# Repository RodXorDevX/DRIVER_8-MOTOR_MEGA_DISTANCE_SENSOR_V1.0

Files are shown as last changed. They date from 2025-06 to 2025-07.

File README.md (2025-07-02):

# DRIVER_8-MOTOR_MEGA_DISTANCE_SENSOR_V1.0

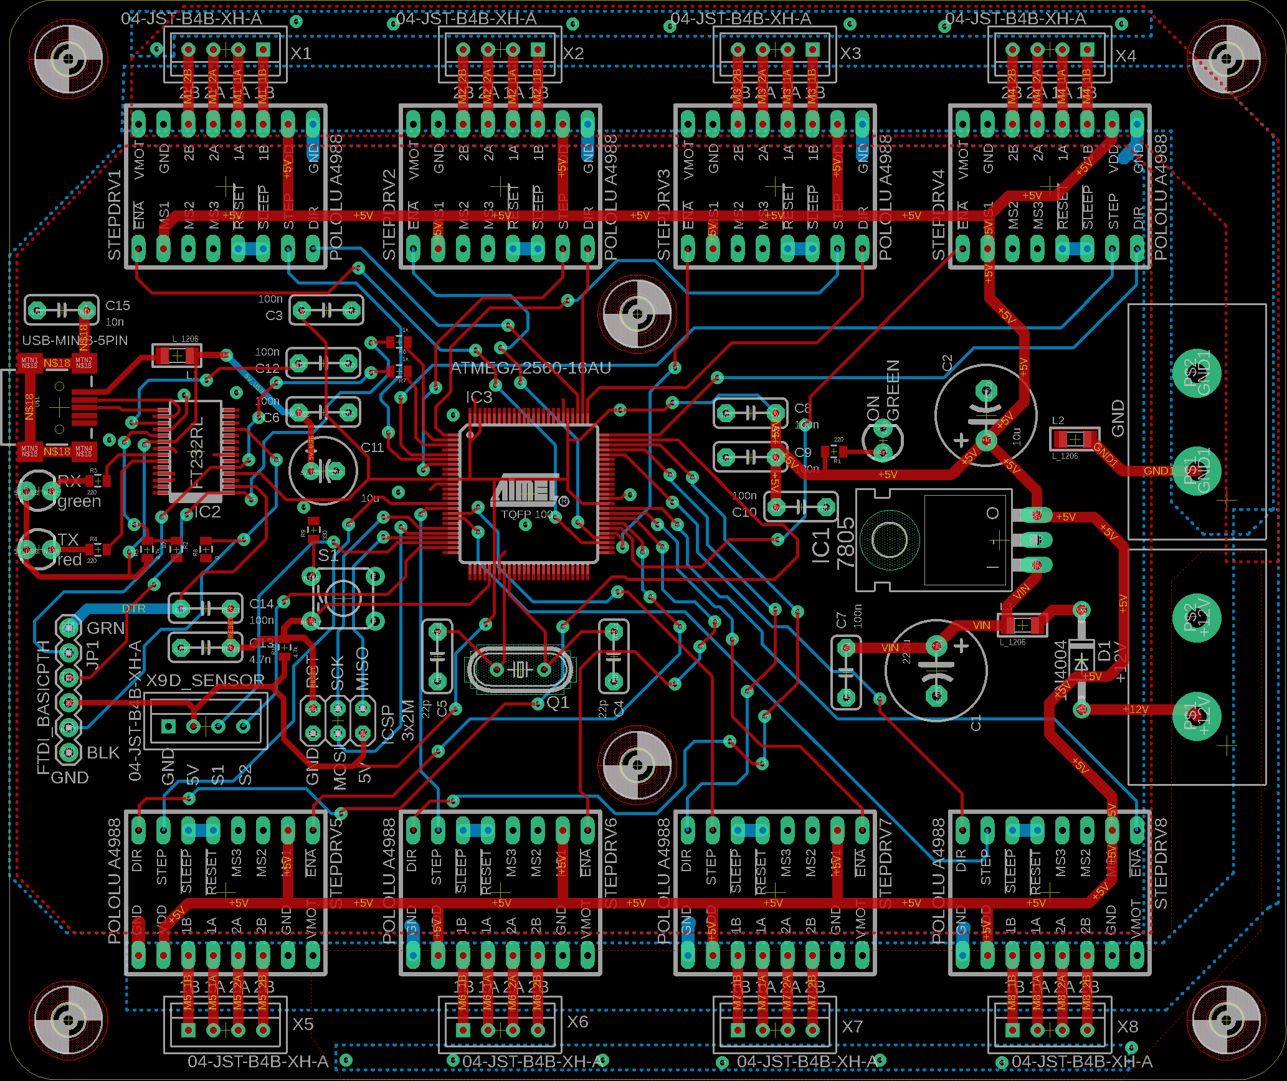
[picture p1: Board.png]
PCB

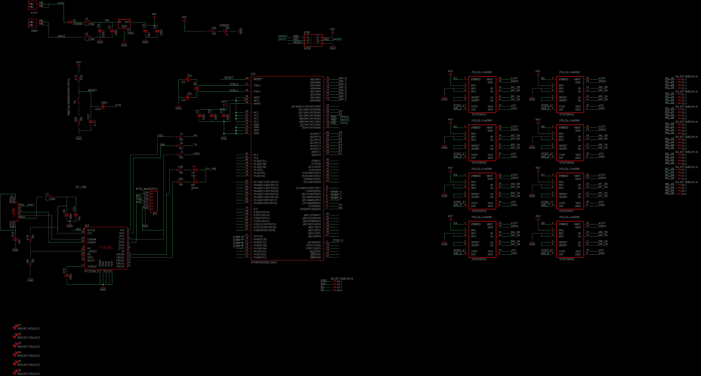
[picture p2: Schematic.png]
Esquemático


## Descripción

Este proyecto consiste en el diseño de una placa electrónica (PCB) para el control de hasta 8 motores y la integración de sensores de distancia, ideal para aplicaciones de robótica, automatización y sistemas embebidos. El diseño está basado en el microcontrolador ATMEGA2560, ampliamente utilizado en plataformas como Arduino MEGA, lo que facilita la programación y expansión del sistema.

La placa permite el uso de módulos para motores paso a paso como el Pololu A4988 o similares, y la conexión de sensores ultrasónicos para la detección de presencia o distancia.

## Aplicación artística

Esta placa fue utilizada en un proyecto de arte donde un cuadro contenía una figura de un anciano en bronce, cuyas partes se desarmaban automáticamente al detectar la presencia de una persona frente al cuadro mediante un sensor ultrasónico. Cuando no se detectaba presencia, el cuadro se rearmaba. También era posible invertir el comportamiento: el cuadro se reordenaba cuando había presencia.

## Características principales

- **Control de 8 motores:** Permite manejar hasta 8 motores de manera independiente mediante módulos A4988 o compatibles.
- **Sensores de distancia:** Integración sencilla de sensores ultrasónicos para medición de distancias o detección de presencia.
- **Microcontrolador ATMEGA2560:** 256 KB de memoria Flash, 8 KB de SRAM, 4 KB de EEPROM, 86 pines de I/O, 16 canales ADC de 10 bits, 12 canales PWM de 16 bits, 4 puertos USART.
- **Conectores estándar:** Pines y headers compatibles con módulos y shields comunes.
- **Archivos Gerber incluidos:** Listos para fabricación profesional de la PCB.

## Archivos incluidos

- `DRIVER_8 MOTOR_MEGA_DISTANCE_SENSOR_V1.0.sch`: Esquemático del circuito.
- `DRIVER_8 MOTOR_MEGA_DISTANCE_SENSOR_V1.0.brd`: Diseño de la PCB.
- Archivos Gerber (`.GBL`, `.GTL`, `.GBO`, `.GTO`, etc.): Para fabricación de la placa.
- `Board.png`: Imagen de la PCB.
- `Schematic.png`: Imagen del esquemático.
- `.TXT`, `.gpi`: Archivos de taladros y detalles de fabricación.

## Uso

1. **Revisión del diseño:** Consulta las imágenes incluidas para visualizar el esquemático y la PCB.
2. **Fabricación:** Utiliza los archivos Gerber para mandar a fabricar la placa en cualquier servicio profesional.
3. **Montaje:** Ensambla los componentes siguiendo el esquemático. Instala los módulos A4988 o similares en los zócalos correspondientes y conecta el sensor ultrasónico en el header designado.
4. **Programación:** Utiliza el entorno de Arduino o AVR para cargar el firmware al ATMEGA2560.

## Créditos

- Diseño original por Rodrigo Urquieta.
- Basado en el microcontrolador ATMEGA2560.

---

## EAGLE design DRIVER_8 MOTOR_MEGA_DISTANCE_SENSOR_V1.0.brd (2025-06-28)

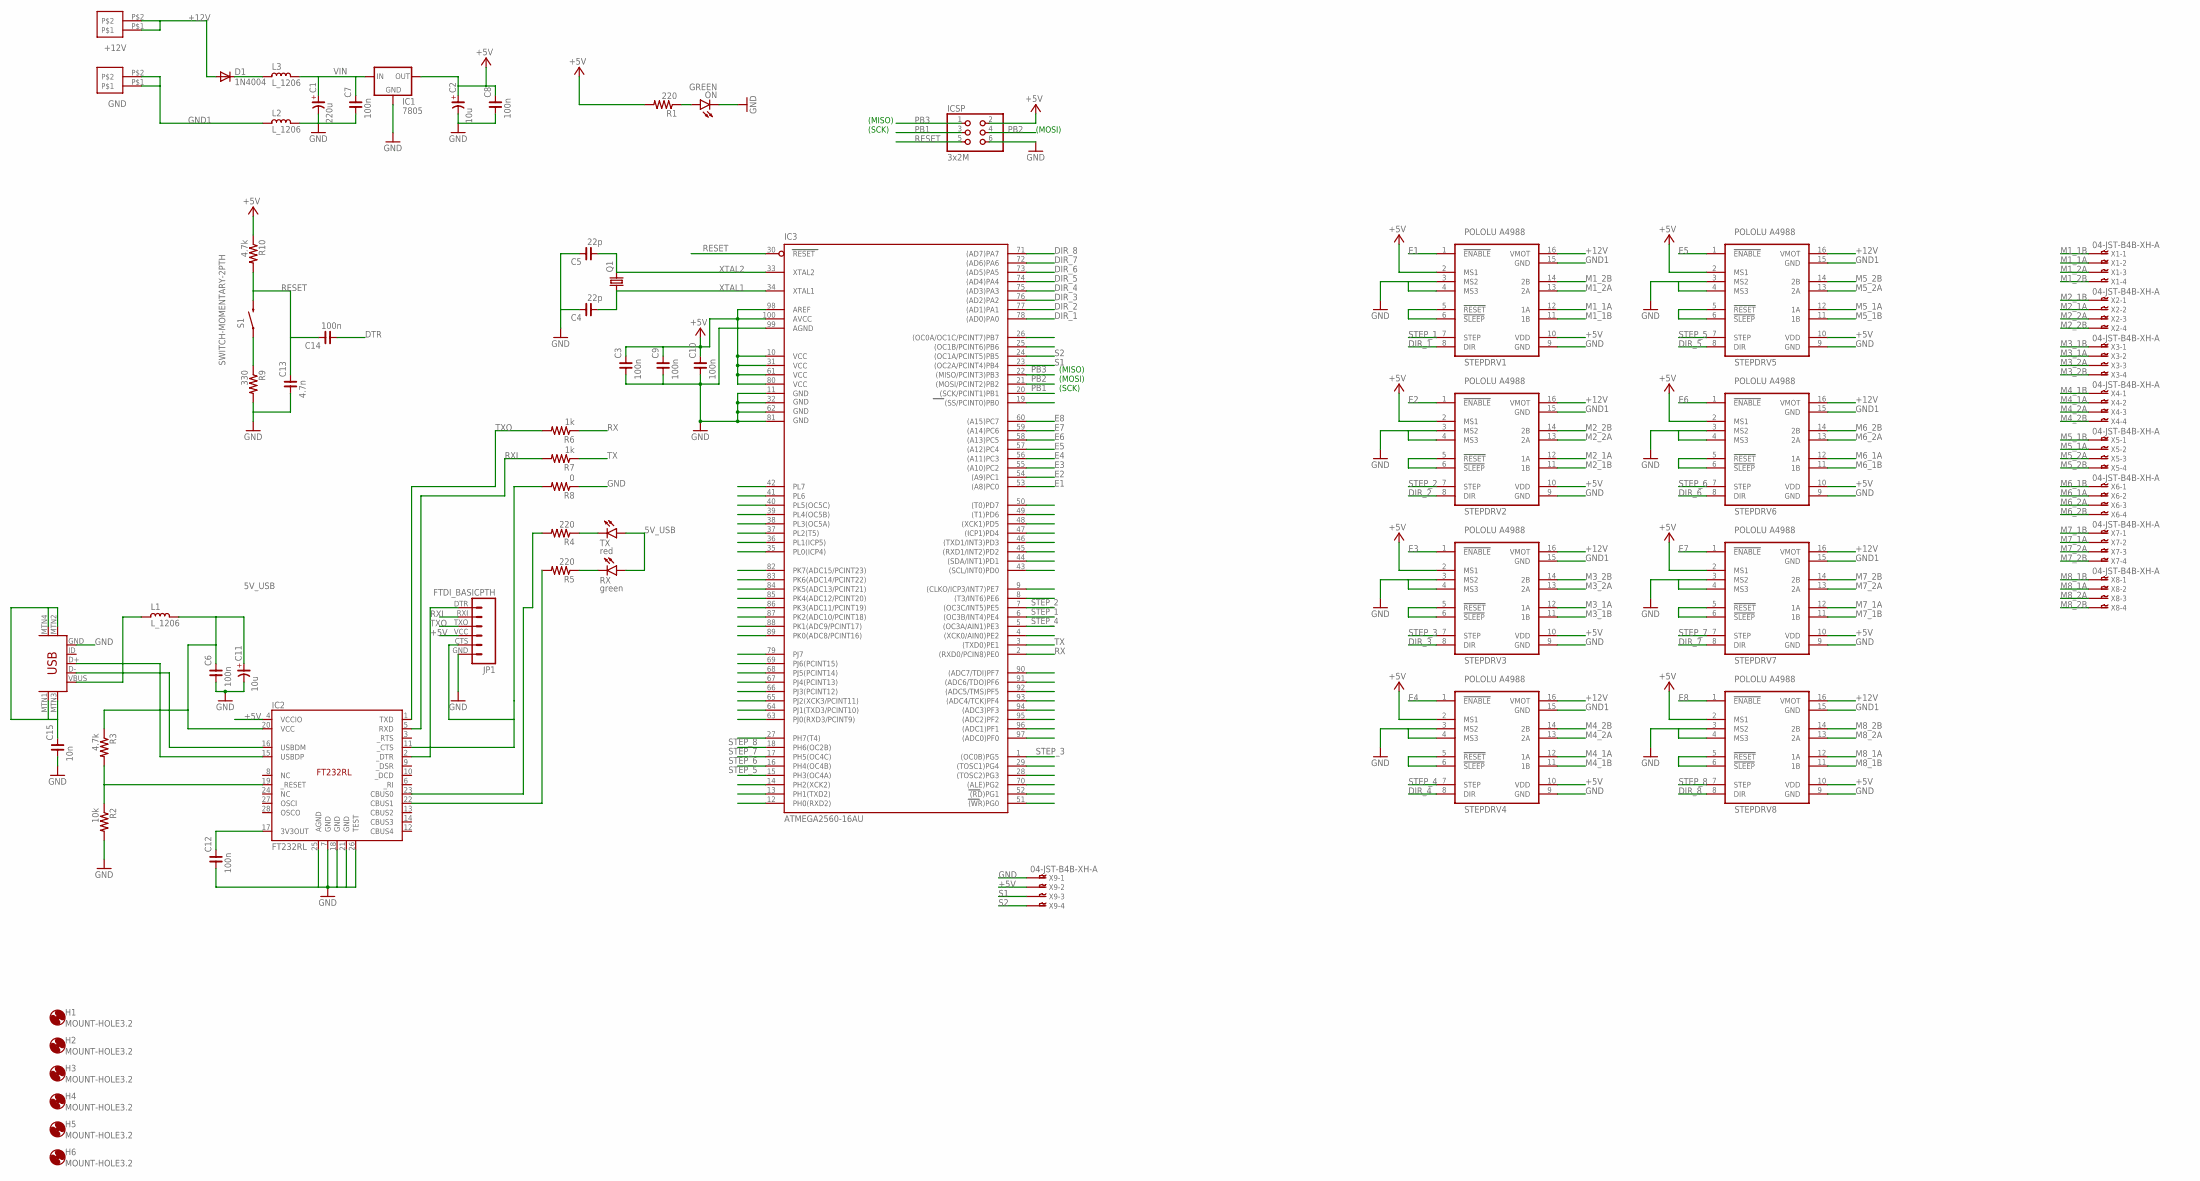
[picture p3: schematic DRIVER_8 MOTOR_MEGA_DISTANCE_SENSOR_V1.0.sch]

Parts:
+12V: SCREW_T_10MM
C1: 220u; CE-050X100
C2: 10u; CE-050X100
C3, C6, C7, C8, C9, C10, C12, C14: 100n; C050-075X030
C4, C5: 22p; C050-075X030
C11: 10u; CE-025X060
C13: 4.7n; C050-075X030
C15: 10n; C050-075X030
D1: 1N4004; DO41-10
GND: SCREW_T_10MM
H1, H2, H3, H4, H5, H6: MOUNT-HOLE3.2; 3,2
IC1: 7805; TO-220-ALT
IC2: FT232RL; SSOP-28
IC3: ATMEGA2560-16AU; TQFP100
ICSP: 3x2M; 2X03
JP1: FTDI_BASICPTH; FTDI_BASIC
L1, L2, L3: L_1206; L1206
ON: GREEN; LED3MM
Q1: CRYSTALHC49S; HC49/S
R1, R4, R5: 220; 0805
R2: 10k; 0805
R3, R10: 4.7k; 0805
R6, R7: 1k; 0805
R8: 0; 0805
R9: 330; 0805
RX: green; LED3MM
S1: SWITCH-MOMENTARY-2PTH; TACTILE-PTH
STEPDRV1, STEPDRV2, STEPDRV3, STEPDRV4, STEPDRV5, STEPDRV6, STEPDRV7, STEPDRV8: POLOLU A4988; POLOLULU2128
TX: red; LED3MM
U$1: USB-MINIB-5PIN; USB-MINIB
X1, X2, X3, X4, X5, X6, X7, X8, X9: 04-JST-B4B-XH-A; B4B-XH

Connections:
5V_USB: C6.2, C11.+, IC2.20 (VCC), L1.1, R3.1, RX.A, TX.A
+5V: C2.+, C3.2, C8.2, C9.2, C10.2, IC1.OUT, IC2.4 (VCCIO), IC3.10 (VCC), IC3.31 (VCC1), IC3.61 (VCC2), IC3.80 (VCC3), IC3.98 (AREF), IC3.100 (AVCC), ICSP.2, JP1.VCC (4), R1.2, R10.1, STEPDRV1.2 (MS1), STEPDRV1.10 (VDD), STEPDRV2.2 (MS1), STEPDRV2.10 (VDD), STEPDRV3.2 (MS1), STEPDRV3.10 (VDD), STEPDRV4.2 (MS1), STEPDRV4.10 (VDD), STEPDRV5.2 (MS1), STEPDRV5.10 (VDD), STEPDRV6.2 (MS1), STEPDRV6.10 (VDD), STEPDRV7.2 (MS1), STEPDRV7.10 (VDD), STEPDRV8.2 (MS1), STEPDRV8.10 (VDD), X9.P$2
+12V: +12V.P$1, +12V.P$2, D1.A, STEPDRV1.16 (VMOT), STEPDRV2.16 (VMOT), STEPDRV3.16 (VMOT), STEPDRV4.16 (VMOT), STEPDRV5.16 (VMOT), STEPDRV6.16 (VMOT), STEPDRV7.16 (VMOT), STEPDRV8.16 (VMOT)
DIR_1: IC3.78 ((AD0)PA0), STEPDRV1.8 (DIR)
DIR_2: IC3.77 ((AD1)PA1), STEPDRV2.8 (DIR)
DIR_3: IC3.76 ((AD2)PA2), STEPDRV3.8 (DIR)
DIR_4: IC3.75 ((AD3)PA3), STEPDRV4.8 (DIR)
DIR_5: IC3.74 ((AD4)PA4), STEPDRV5.8 (DIR)
DIR_6: IC3.73 ((AD5)PA5), STEPDRV6.8 (DIR)
DIR_7: IC3.72 ((AD6)PA6), STEPDRV7.8 (DIR)
DIR_8: IC3.71 ((AD7)PA7), STEPDRV8.8 (DIR)
DTR: C14.1, IC2.2 (_DTR), JP1.DTR (1)
E1: IC3.53 ((A8)PC0), STEPDRV1.1 (!ENABLE)
E2: IC3.54 ((A9)PC1), STEPDRV2.1 (!ENABLE)
E3: IC3.55 ((A10)PC2), STEPDRV3.1 (!ENABLE)
E4: IC3.56 ((A11)PC3), STEPDRV4.1 (!ENABLE)
E5: IC3.57 ((A12)PC4), STEPDRV5.1 (!ENABLE)
E6: IC3.58 ((A13)PC5), STEPDRV6.1 (!ENABLE)
E7: IC3.59 ((A14)PC6), STEPDRV7.1 (!ENABLE)
E8: IC3.60 ((A15)PC7), STEPDRV8.1 (!ENABLE)
GND: C1.-, C2.-, C3.1, C4.2, C5.2, C6.1, C7.1, C8.1, C9.1, C10.1, C11.-, C12.1, C13.1, C15.1, IC1.GND, IC2.7 (GND), IC2.18 (GND), IC2.21 (GND), IC2.25 (AGND), IC2.26 (TEST), IC3.11 (GND), IC3.32 (GND1), IC3.62 (GND2), IC3.81 (GND3), IC3.99 (AGND), ICSP.6, JP1.GND (6), L2.1, ON.K (C), R2.2, R8.1, R9.2, STEPDRV1.3 (MS2), STEPDRV1.4 (MS3), STEPDRV1.9 (GND), STEPDRV2.3 (MS2), STEPDRV2.4 (MS3), STEPDRV2.9 (GND), STEPDRV3.3 (MS2), STEPDRV3.4 (MS3), STEPDRV3.9 (GND), STEPDRV4.3 (MS2), STEPDRV4.4 (MS3), STEPDRV4.9 (GND), STEPDRV5.3 (MS2), STEPDRV5.4 (MS3), STEPDRV5.9 (GND), STEPDRV6.3 (MS2), STEPDRV6.4 (MS3), STEPDRV6.9 (GND), STEPDRV7.3 (MS2), STEPDRV7.4 (MS3), STEPDRV7.9 (GND), STEPDRV8.3 (MS2), STEPDRV8.4 (MS3), STEPDRV8.9 (GND), U$1.GND, X9.P$1
GND1: GND.P$1, GND.P$2, L2.2, STEPDRV1.15 (GND), STEPDRV2.15 (GND), STEPDRV3.15 (GND), STEPDRV4.15 (GND), STEPDRV5.15 (GND), STEPDRV6.15 (GND), STEPDRV7.15 (GND), STEPDRV8.15 (GND)
M1_1A: STEPDRV1.12 (1A), X1.P$2
M1_1B: STEPDRV1.11 (1B), X1.P$1
M1_2A: STEPDRV1.13 (2A), X1.P$3
M1_2B: STEPDRV1.14 (2B), X1.P$4
M2_1A: STEPDRV2.12 (1A), X2.P$2
M2_1B: STEPDRV2.11 (1B), X2.P$1
M2_2A: STEPDRV2.13 (2A), X2.P$3
M2_2B: STEPDRV2.14 (2B), X2.P$4
M3_1A: STEPDRV3.12 (1A), X3.P$2
M3_1B: STEPDRV3.11 (1B), X3.P$1
M3_2A: STEPDRV3.13 (2A), X3.P$3
M3_2B: STEPDRV3.14 (2B), X3.P$4
M4_1A: STEPDRV4.12 (1A), X4.P$2
M4_1B: STEPDRV4.11 (1B), X4.P$1
M4_2A: STEPDRV4.13 (2A), X4.P$3
M4_2B: STEPDRV4.14 (2B), X4.P$4
M5_1A: STEPDRV5.12 (1A), X5.P$2
M5_1B: STEPDRV5.11 (1B), X5.P$1
M5_2A: STEPDRV5.13 (2A), X5.P$3
M5_2B: STEPDRV5.14 (2B), X5.P$4
M6_1A: STEPDRV6.12 (1A), X6.P$2
M6_1B: STEPDRV6.11 (1B), X6.P$1
M6_2A: STEPDRV6.13 (2A), X6.P$3
M6_2B: STEPDRV6.14 (2B), X6.P$4
M7_1A: STEPDRV7.12 (1A), X7.P$2
M7_1B: STEPDRV7.11 (1B), X7.P$1
M7_2A: STEPDRV7.13 (2A), X7.P$3
M7_2B: STEPDRV7.14 (2B), X7.P$4
M8_1A: STEPDRV8.12 (1A), X8.P$2
M8_1B: STEPDRV8.11 (1B), X8.P$1
M8_2A: STEPDRV8.13 (2A), X8.P$3
M8_2B: STEPDRV8.14 (2B), X8.P$4
unnamed: L1.2, U$1.VBUS
unnamed: IC2.16 (USBDM), U$1.D-
unnamed: ON.A, R1.1
unnamed: STEPDRV2.5 (!RESET), STEPDRV2.6 (!SLEEP)
unnamed: STEPDRV3.5 (!RESET), STEPDRV3.6 (!SLEEP)
unnamed: IC2.15 (USBDP), U$1.D+
unnamed: STEPDRV1.5 (!RESET), STEPDRV1.6 (!SLEEP)
unnamed: STEPDRV4.5 (!RESET), STEPDRV4.6 (!SLEEP)
unnamed: STEPDRV5.5 (!RESET), STEPDRV5.6 (!SLEEP)
unnamed: STEPDRV6.5 (!RESET), STEPDRV6.6 (!SLEEP)
unnamed: STEPDRV7.5 (!RESET), STEPDRV7.6 (!SLEEP)
unnamed: STEPDRV8.5 (!RESET), STEPDRV8.6 (!SLEEP)
unnamed: C12.2, IC2.17 (3V3OUT)
unnamed: D1.C, L3.2
unnamed: R4.1, TX.K (C)
unnamed: R5.1, RX.K (C)
unnamed: C15.2, U$1.MTN1 (MTN2), U$1.MTN2 (MTN3), U$1.MTN3 (MTN1), U$1.MTN4
unnamed: IC2.23 (CBUS0), R4.2
unnamed: IC2.22 (CBUS1), R5.2
unnamed: IC2.11 (_CTS), JP1.CTS (5), R8.2
unnamed: R9.1, S1.1
unnamed: IC2.19 (_RESET), R2.1, R3.2
PB0: IC3.19 ((SS/PCINT0)PB0)
PB1: IC3.20 ((SCK/PCINT1)PB1), ICSP.3
PB2: IC3.21 ((MOSI/PCINT2)PB2), ICSP.4
PB3: IC3.22 ((MISO/PCINT3)PB3), ICSP.1
PB6: IC3.25 ((OC1B/PCINT6)PB6)
PB7: IC3.26 ((OC0A/OC1C/PCINT7)PB7)
PD7: IC3.50 ((T0)PD7)
PG0: IC3.51 ((WR)PG0)
PG1: IC3.52 ((RD)PG1)
PG2: IC3.70 ((ALE)PG2)
PL0: IC3.35 (PL0(ICP4))
PL1: IC3.36 (PL1(ICP5))
PL2: IC3.37 (PL2(T5))
PL3: IC3.38 (PL3(OC5A))
PL4: IC3.39 (PL4(OC5B))
PL5: IC3.40 (PL5(OC5C))
PL6: IC3.41 (PL6)
PL7: IC3.42 (PL7)
RESET: C13.2, C14.2, IC3.30 (RESET), ICSP.5, R10.2, S1.3 (2)
RX: IC3.2 ((RXD0/PCIN8)PE0), R6.1
RXD2: IC3.12 (PH0(RXD2))
RXD3: IC3.63 (PJ0(RXD3/PCINT9))
RXI: IC2.5 (RXD), JP1.RXI (2), R7.2
S1: IC3.23 ((OC2A/PCINT4)PB4), X9.P$3
S2: IC3.24 ((OC1A/PCINT5)PB5), X9.P$4
STEP_1: IC3.6 ((OC3B/INT4)PE4), STEPDRV1.7 (STEP)
STEP_2: IC3.7 ((OC3C/INT5)PE5), STEPDRV2.7 (STEP)
STEP_3: IC3.1 ((OC0B)PG5), STEPDRV3.7 (STEP)
STEP_4: IC3.5 ((OC3A/AIN1)PE3), STEPDRV4.7 (STEP)
STEP_5: IC3.15 (PH3(OC4A)), STEPDRV5.7 (STEP)
STEP_6: IC3.16 (PH4(OC4B)), STEPDRV6.7 (STEP)
STEP_7: IC3.17 (PH5(OC4C)), STEPDRV7.7 (STEP)
STEP_8: IC3.18 (PH6(OC2B)), STEPDRV8.7 (STEP)
TX: IC3.3 ((TXD0)PE1), R7.1
TXD2: IC3.13 (PH1(TXD2))
TXD3: IC3.64 (PJ1(TXD3/PCINT10))
TXO: IC2.1 (TXD), JP1.TXO (3), R6.2
VIN: C1.+, C7.2, IC1.IN, L3.1
XTAL1: C4.1, IC3.34 (XTAL1), Q1.1
XTAL2: C5.1, IC3.33 (XTAL2), Q1.2

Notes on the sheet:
(SCK)
(MISO)
(MOSI)

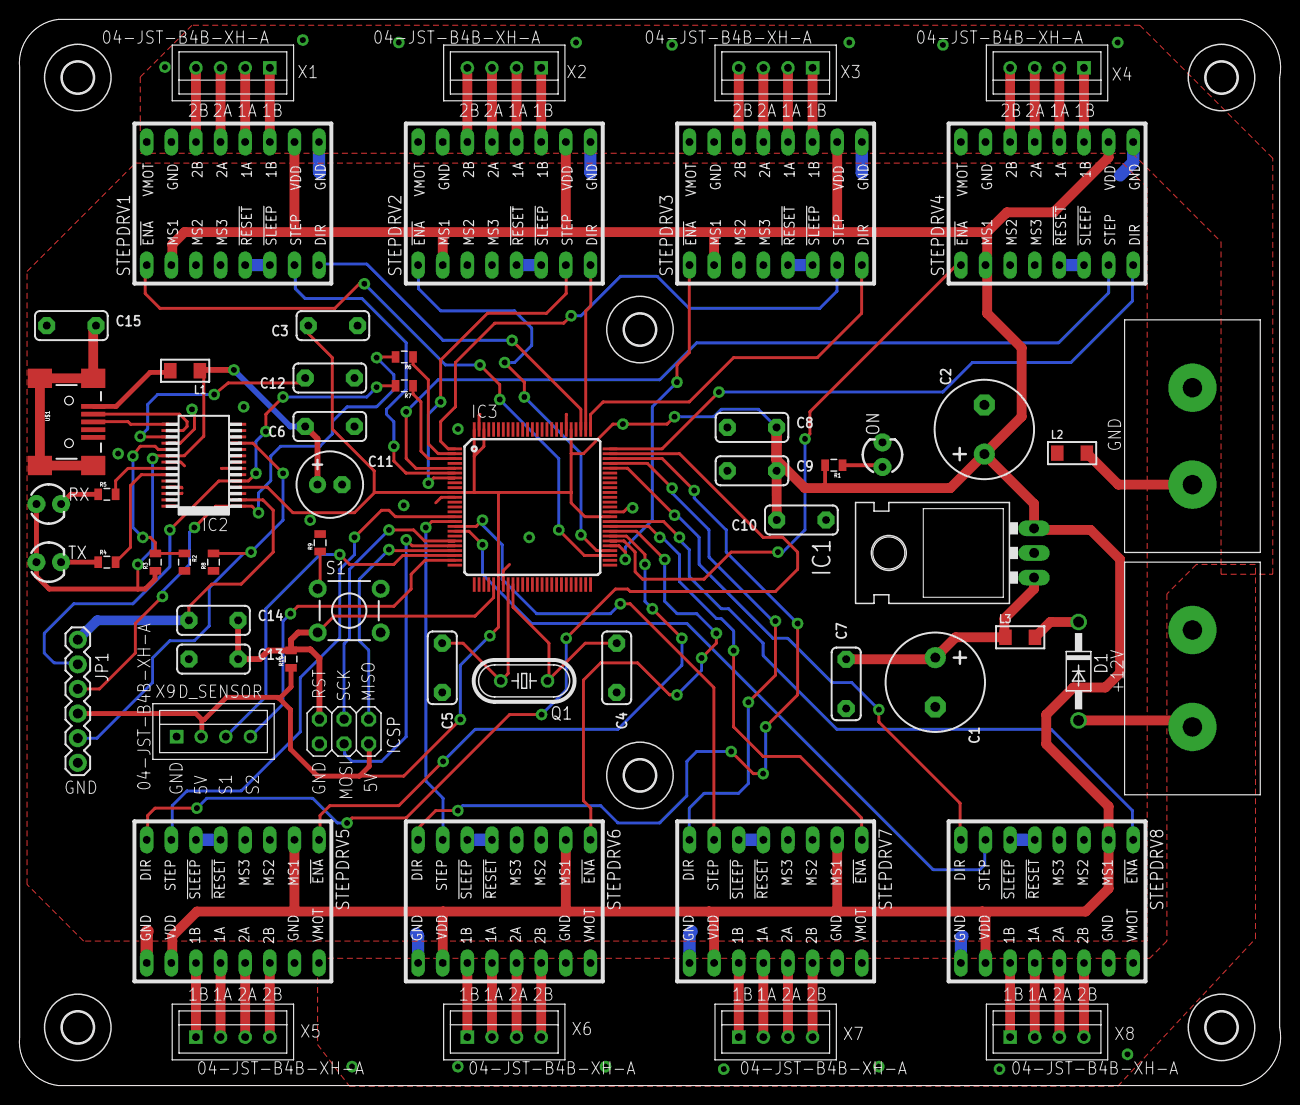
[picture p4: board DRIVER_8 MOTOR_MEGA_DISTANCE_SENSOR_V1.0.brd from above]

Board: 2 copper layers, 130.1 x 110.0 mm, 65 parts (0 on the bottom side), 97 nets.

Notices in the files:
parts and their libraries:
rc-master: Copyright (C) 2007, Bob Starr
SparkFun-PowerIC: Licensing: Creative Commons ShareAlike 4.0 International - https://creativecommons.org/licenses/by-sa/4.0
